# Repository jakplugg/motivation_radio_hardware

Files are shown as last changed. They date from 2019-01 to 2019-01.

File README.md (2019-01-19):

# Motivation Radio
Motivation radio hardware Is The board for Rich Heslip's ESP32 based eurorack breakout module.

Currently there is no "standard" software release for it, you can use the arduino IDE with ESP32 [arduino core](https://github.com/espressif/arduino-esp32) if you want to develop something yourself!

software can be found at his repositories here. (more to come as it is developed)
[rheslip](https://github.com/rheslip)

8Hp eurorack module.

128x32 display and encoder.

I/O:

* 4 CV out with 12 bit external DAC
* 4 digital (gate. trig, clock etc) out.
* 4 CV in with 12 bit external ADC
* 4 digital in
* MIDI IN
* MIDI OUT

JM.

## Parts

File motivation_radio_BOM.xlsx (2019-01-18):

RefDes | Qty | Value | Description | Package | Mouser | Notes
R18, R19 | 2 | 100 | Resistor, 5% | 1206 | 71-CRCW1206100RJNEAC
R17 | 1 | 220 | Resistor, 1% | 0603 | 71-CRCW0603220RFKEBC
R20 | 1 | 470 | Resistor, 1% | 0603 | 603-RC0603FR-07470RL
R21, R38, R39, R40, R41, R51, R52, R53, R56 | 9 | 1.0k | Resistor, 1% | 0603 | 667-ERJ-3EKF1001V
R9, R11 | 2 | 3.3k | Resistor, 1% (see note) | 0603 | 603-RC0603FR-073K3L | not required if OLED module has pullups - most do
R1, R4, R7, R12,R16,R15 | 6 | 10k | Resistor, 1% | 0603 | 667-ERJ-3EKF1002V
R26, R27, R28, R29 | 4 | 30k | Resistor, 1% | 0603 | 603-RC0603FR-0730KL
R2, R3, R5, R6, R8, R10, R13, R14, R30, R31, R32, R33,R34, R35, R36, R37, R42, R43, R44, R45,R46,R47,R48,R57 | 24 | 100k | Resistor, 1% | 0603 | 667-ERJ-3EKF1003V
R22, R23, R24, R25,R49,R50,R54,R55 | 8 | 200k | Resistor, 1% | 0603 | 603-RC0603FR-07200KL
C23, C24, C25, C27,C32, C34, C35, C36 | 8 | 100p | Capacitor, >=16V | 0603 | 603-CC603KRX7R7BB101
C14, C15,C16,C17 | 4 | 470p | Capacitor, >=16V | 0603 | 603-CC603KRX7R7BB471
C1, C4,C7,C10, C13, C18,C19,C20, C21, C22, C28, C29, C30, C31, C37, C38, C39 | 17 | 100n | Capacitor, >=16V | 0603 | 81-GRM188R71E104JA1J | Murata GRM188R71E104JA01J
C11, C12 | 2 | 470n | Capacitor, >=16V | 0603 | 603-CC603MRY5V7BB474 | Yageo CC0603MRY5V7BB474
C6, C8 | 2 | 1u | Capacitor, >=16V | 0603 | 963-EMK107B7105KAHT
C2, C3 | 2 | 22u | Capacitor, >=16V | 1206 | 81-GRM31CR61E226ME5L | Murata GRM31CR61E226ME15L | GRT31CC81C226KE01L
C5, C26, C33 | 3 | 22u | Capacitor, >=16V |  | 667-EEE-FP1V220AR
C9 | 1 | 47u | Capacitor, >=10V |  | 667-EEE-FK1V470P
L1, L2, L4 | 3 |  | ferrite bead | 0603 | 710-742792664 | Würth Electronics 742792664
L3 | 1 | 33u | inductor | 0805 | 810-MLZ2012M330WT000 | TDK MLZ2012M330WT000
D1, D2, D6 | 3 | 1N5819HW | Schottky diode | SOD123 | 621-1N5819HW-F | Diodes Inc 1N5819HW-7-F
D3, D4, D5 | 3 | BAT54S | Dual Schottky diode | SOT23 | 512-BAT54S | BAT54S
Q1, Q2, Q3, Q4 | 4 | MMBT3904 | NPN transistor | SOT23 | 863-MMBT3904LT1G | On Semi MMBT3904LT1G | Fairchild MMBT3904
IC1 | 1 | R-78E5.0-0.5 | 5V switching regulator |  | 919-R-78E5.0-0.5 | RECOM R-78E5.0-0.5
IC2 | 1 | MIC5504-3.3YM5 | 3.3v Regulator | SOT23-5 | 998-MIC5504-3.3YM5TR | Microchip MIC5504-3.3YM5-TR
IC3 | 1 | LM4040B3 | 3V reference | SOT23 | 621-LM4040B30QFTA
IC4 | 1 | LM4040B10 | 10V reference | SOT23 | 595-LM4040C10IDBZR | Texas Instruments LM4040C10IDBZ
IC5, IC6 | 2 | MCP4822 | Dual SPI DAC | SOIC8 | 579-MCP4822-E/SN | Microchip MCP4822-E/SN
U1 | 1 | MCP3204 | 4 channel A/D converter | TSSOP-14 | 579-MCP3204-CI/ST | Microchip MCP3204-CI/ST
U2, U3 | 2 | MCP6002 | MCP6002 dual op-amp R2R IO | SOIC8 | 579-MCP6002-I/SN | MCP6002-I/SN
U4, U5 | 2 | TL072 | dual op amp | SOIC8 | 595-TL072CD
U6, U7 | 2 | OPA2171 | dual precision op amp | SOIC8 | 595-OPA2171AIDR | TI OPA2171AIDR
U8 | 1 |  | OLED module | 128x32 OLED .9" I2C |  | Aliexpress | https://www.aliexpress.com/item/1pcs-0-91-inch-OLED-module-0-91-white-blue-OLED-128X32-OLED-LCD-LED-Display/32672229793.html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
OK1 | 1 | HCPL-0600 | opto isolator | HCPL0600 (6N137) | 630-HCPL-0600-000E | Broadcom HCPL-0600-000E
J1, J2 | 2 |  | vertical stereo jack | PJ301CM |  | 806-STPX-3501-3N-1
J3, J4, J5, J6, J7, J8, J9, J10, J11, J12, J13, J14, J15, J16, J17, J18 | 16 |  | vertical mono jack | PJ301_THONKICONN
JP1 | 1 |  | 2x5 male header, 2.54mm pitch |  | 649-67996-410HLF
MODULE1 | 1 |  | ESP32 Dev module | ESP32DEVKITC | 356-ESP32-DEVKITC
SW1 | 1 |  | Rotary Encoder with switch | EC12E_SW | 858-EN11-HSM1BF20 (http://www.mouser.com/ProductDetail/TT-Electronics/EN11-HSM1BF20/) | Aliexpress | https://www.aliexpress.com/item/Original-Rotary-encoder-code-switch-EC11-audio-digital-potentiometer-with-switch-5Pin-handle-length-20mm-free/1669874082.html
Sockets | 2 |  | 19 pin .1" sockets for ESP module |  |  | can buy 40 pin and cut to length | https://www.aliexpress.com/item/10PCS-1X40-PIN-Single-Row-Straight-FEMALE-PIN-HEADER-2-54MM-PITCH-Strip-Connector-Socket-140/32861400498.html

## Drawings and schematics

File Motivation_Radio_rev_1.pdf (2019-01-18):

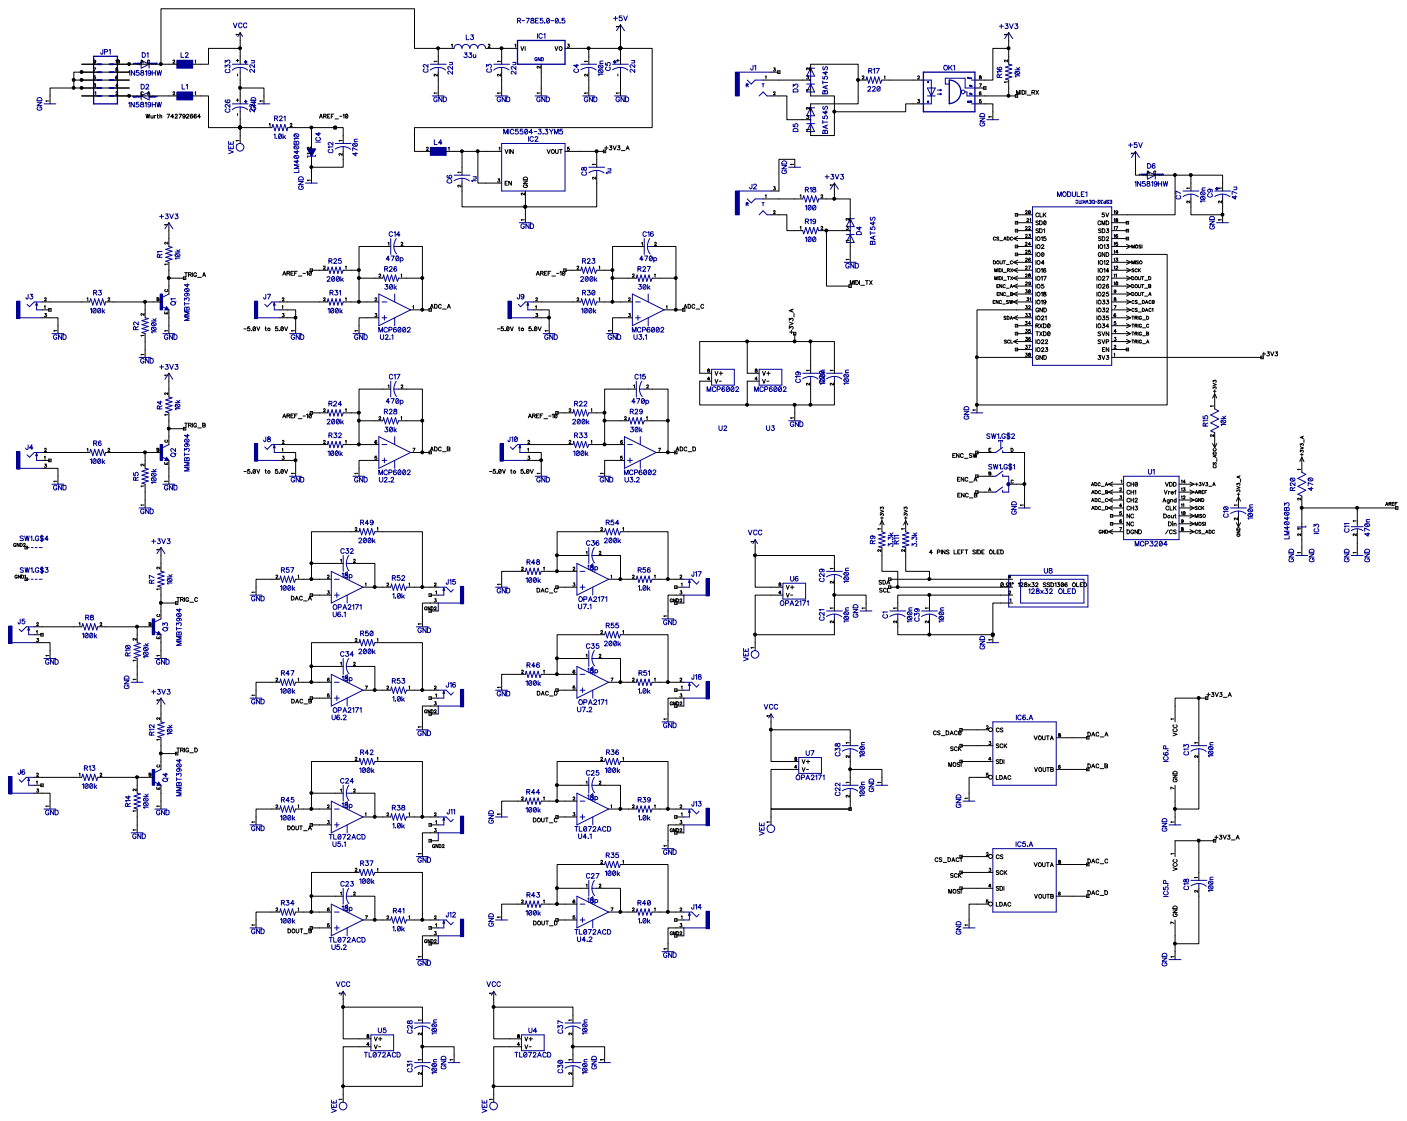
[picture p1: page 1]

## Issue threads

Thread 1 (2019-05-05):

Part for J1,J2 (stereo jack)

Jagmills, 2019-05-05:
Hi!
I think the part number listed in the BOM for J1 and J2 is incorrect (based on shopping at Thonk). It is currently listed as PJ301CM, which has 2 pins in line and one at a right angle - whereas PJ366ST has all pins in a row, same as the mono jacks used and compatible with the stereo jack PCB footprints.

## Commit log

2019-01-18 initial upload
    first release
    [ESP.sch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]
2019-01-19 edit readme
    [Pin_map.xlsx]
